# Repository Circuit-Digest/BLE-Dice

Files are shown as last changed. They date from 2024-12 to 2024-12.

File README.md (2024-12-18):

# [BLE-Dice](https://circuitdigest.com/microcontroller-projects/how-to-build-a-smart-led-dice)
An electronics dice with BluetoothLE connectivity.
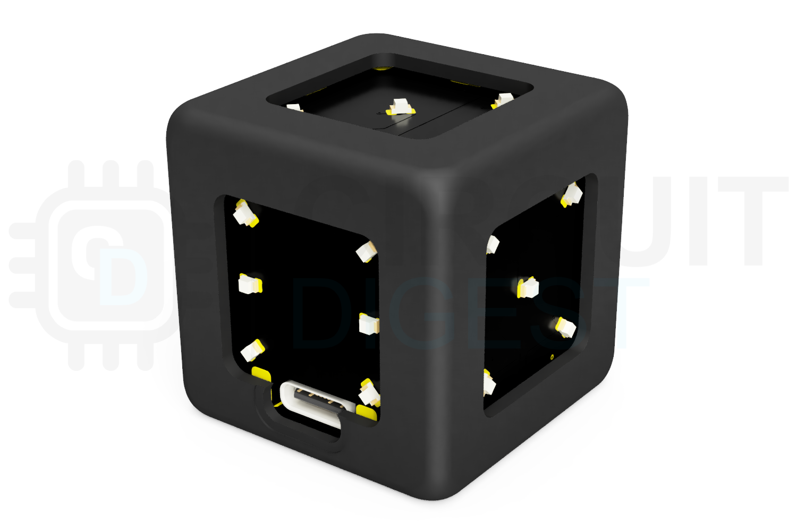
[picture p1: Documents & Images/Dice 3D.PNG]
image_tooltip

<br>

<br>

<br>

[<h1>Click here](https://circuitdigest.com/tags/ESP32) For other ESP32 tutorials.</h1>

<br>
<br>
<br>

<br>
[Note: As this project is very simple we are only providing the code, schematic, and a few essential images if you want to get the images or code explanations do check out the Circuit Digest website.
<br>
<br>

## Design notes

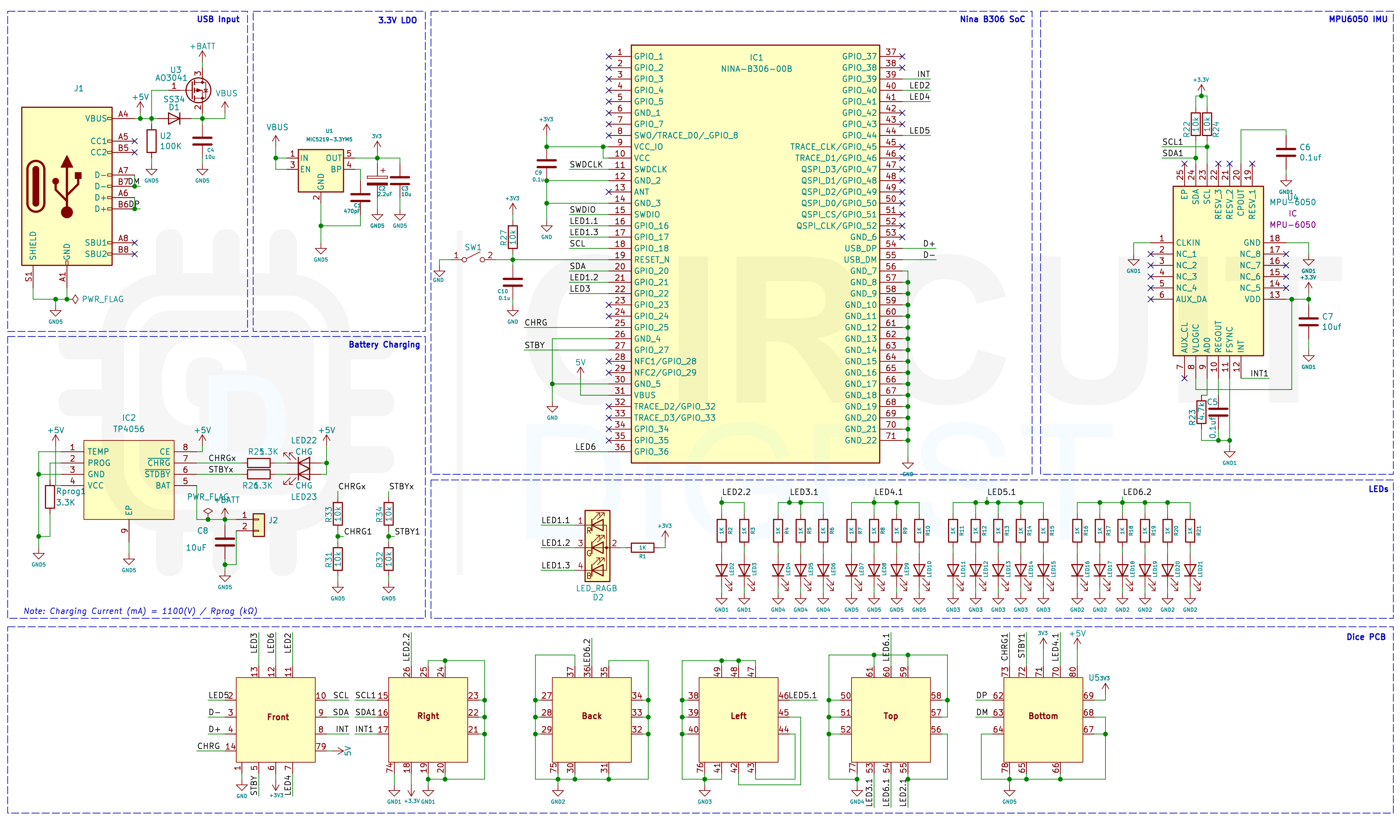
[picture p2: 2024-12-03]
Documents & Images/BLE Dice Schematics.png

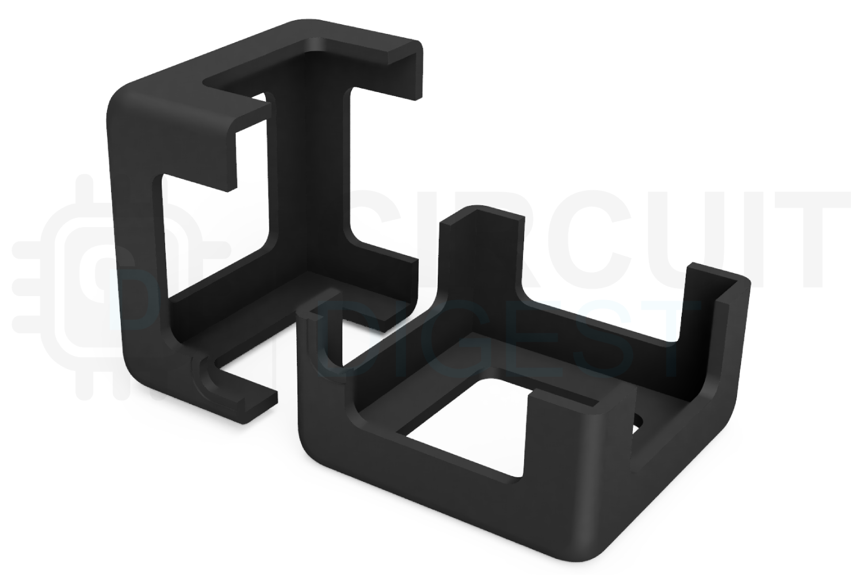
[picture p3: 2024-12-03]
Documents & Images/Dice2_Enc.png

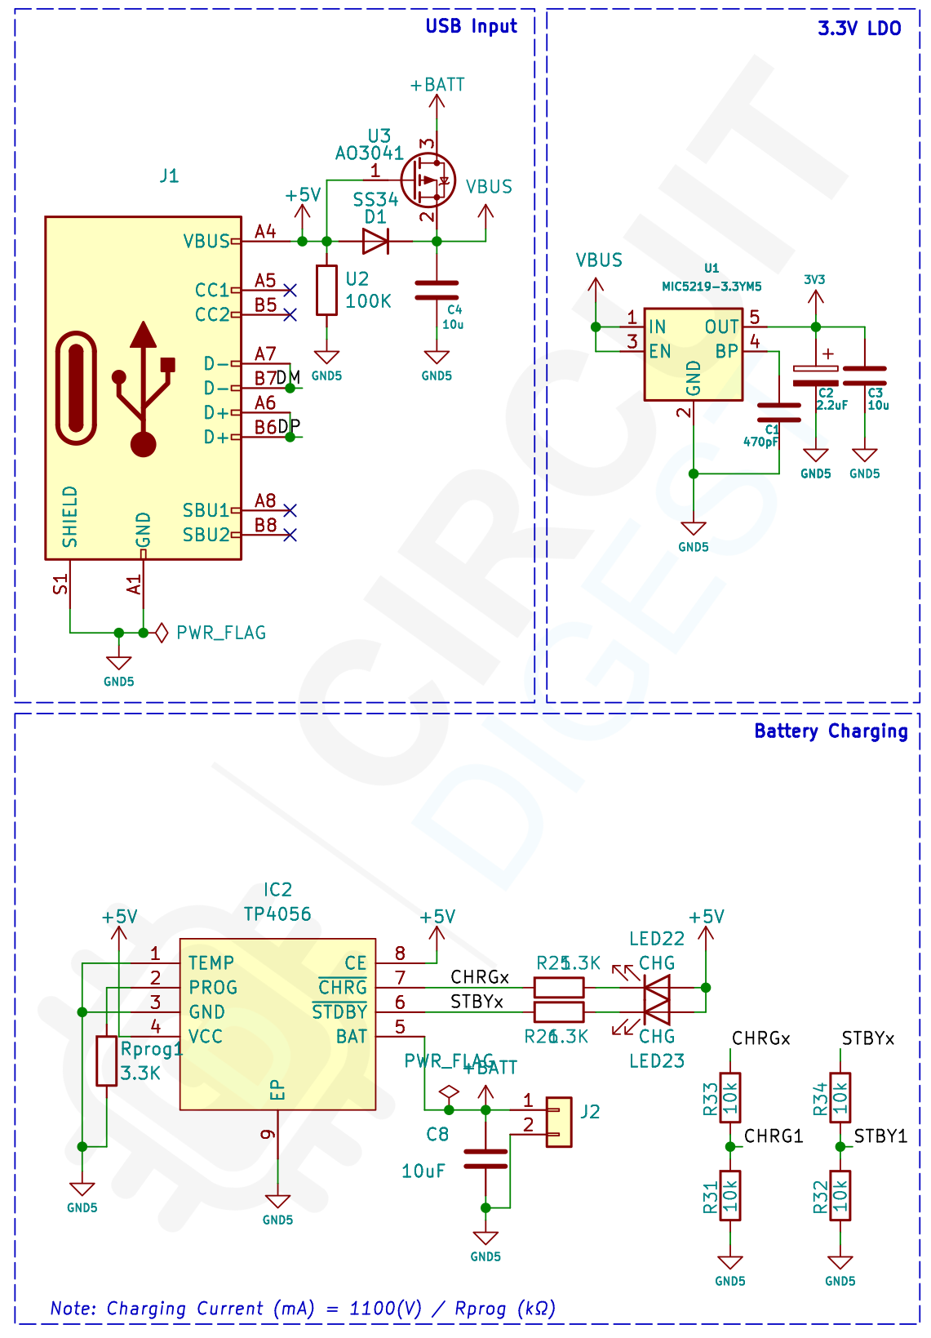
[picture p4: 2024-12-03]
Documents & Images/BLE Dice Power.png

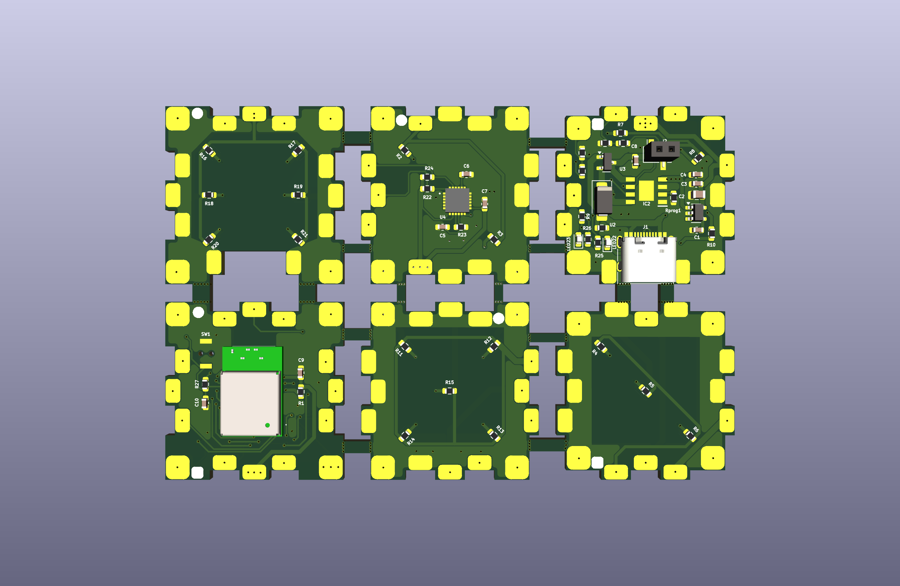
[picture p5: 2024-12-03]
Documents & Images/DiceTop3D.png

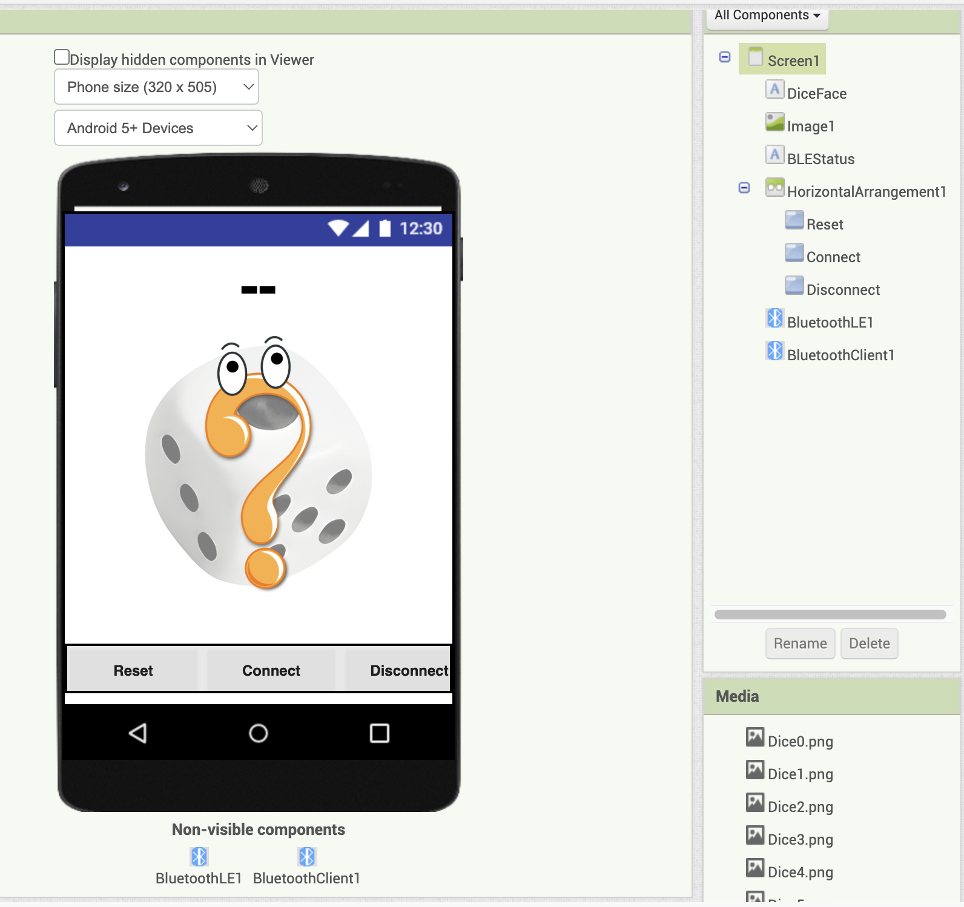
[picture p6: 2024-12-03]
Documents & Images/BLE Dice MIT app Invenotr UI.png

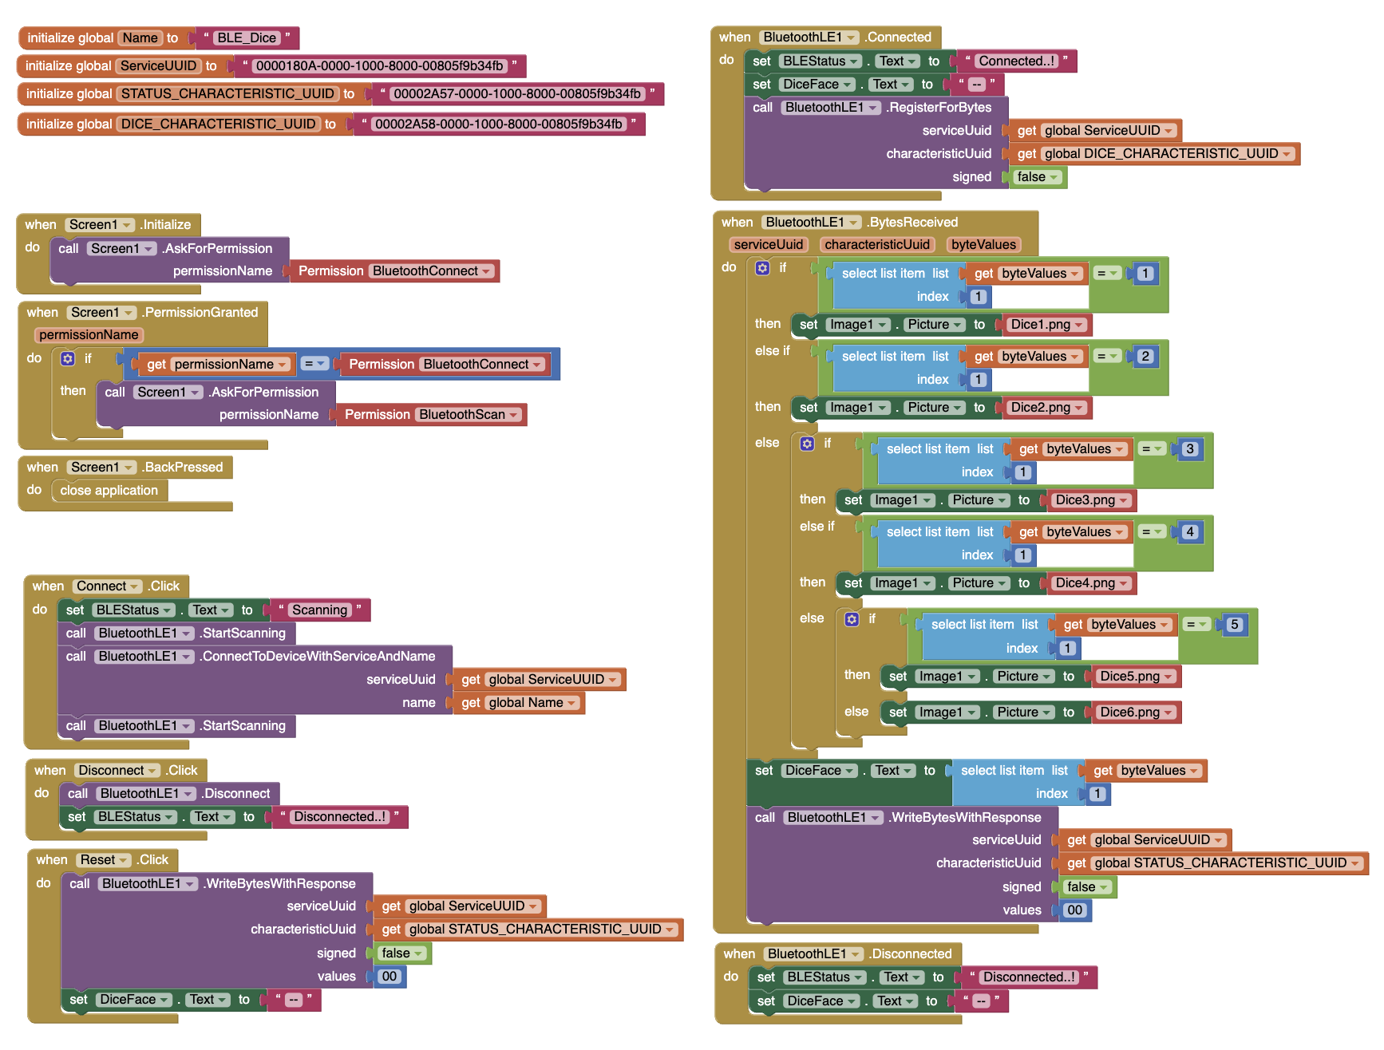
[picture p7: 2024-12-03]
Documents & Images/BLE Dice MIT App inventor Blocks.png

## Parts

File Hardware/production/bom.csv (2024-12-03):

Designator | Footprint | Quantity | Value | LCSC Part #
C1 | 0603 | 1 | 470pF
C10, C9 | 0603 | 2 | 0.1u
C2 | 0805 | 1 | 2.2uF
C3, C4 | 0603 | 2 | 10u
C5, C6 | 0603 | 2 | 0.1uf
C7, C8 | 0603 | 2 | 10uf
D1 | D_SMA | 1 | SS34
D2 | LED-ARRAY-SMD_4P-L1.6-W1.5-BR_XL-1615RGBC-RF | 1 | LED_RAGB
IC1 | NINAB30600B | 1 | NINA-B306-00B
IC2 | SOIC127P600X175-9N | 1 | TP4056
J1 | USB_C_Receptacle_HRO_TYPE-C-31-M-12 | 1 | USB_C_Receptacle_USB2.0
J2 | PinSocket_1x02_P2.00mm_Vertical_SMD_Pin1Right | 1 | B2B-PH-SM4-TB(LF)(SN)
LED10, LED11, LED12, LED13, LED14, LED15, LED16, LED17, LED18, LED19, LED2, LED20, LED21, LED3, LED4, LED5, LED6, LED7, LED8, LED9 | 0805 | 20 | POW_LED
LED22, LED23 | 0603 | 2 | CHG
R1, R10, R11, R12, R13, R14, R15, R16, R17, R18, R19, R2, R20, R21, R3, R4, R5, R6, R7, R8, R9 | 0603 | 21 | 1K
R22, R24, R27, R31, R32, R33, R34 | 0603 | 7 | 10k
R23 | 0603 | 1 | 4.7k
R25, R26 | 0603 | 2 | 1.3K
Rprog1 | 0603 | 1 | 3.3K
SW1 | Tactile 3x4x2mm TS-A010 | 1 | TS-1088R-02526
U1 | SOT-23-5 | 1 | MIC5219-3.3YM5
U2 | 0603 | 1 | 100K
U3 | SOT-23 | 1 | AO3041
U4 | MPU6050 | 1 | MPU-6050
U5 | Cube | 1 | ~

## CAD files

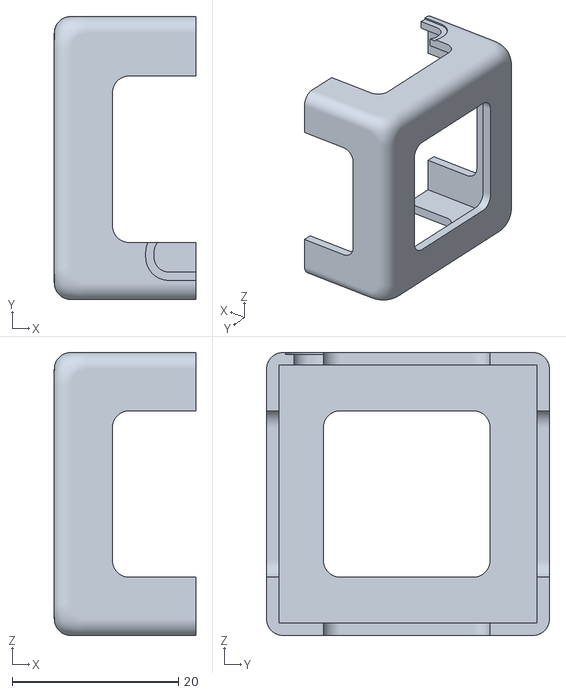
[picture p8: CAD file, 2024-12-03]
3D Printed Parts/Part2.stl
17.0 x 34.0 x 34.0

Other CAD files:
3D Printed Parts/Part1.stl

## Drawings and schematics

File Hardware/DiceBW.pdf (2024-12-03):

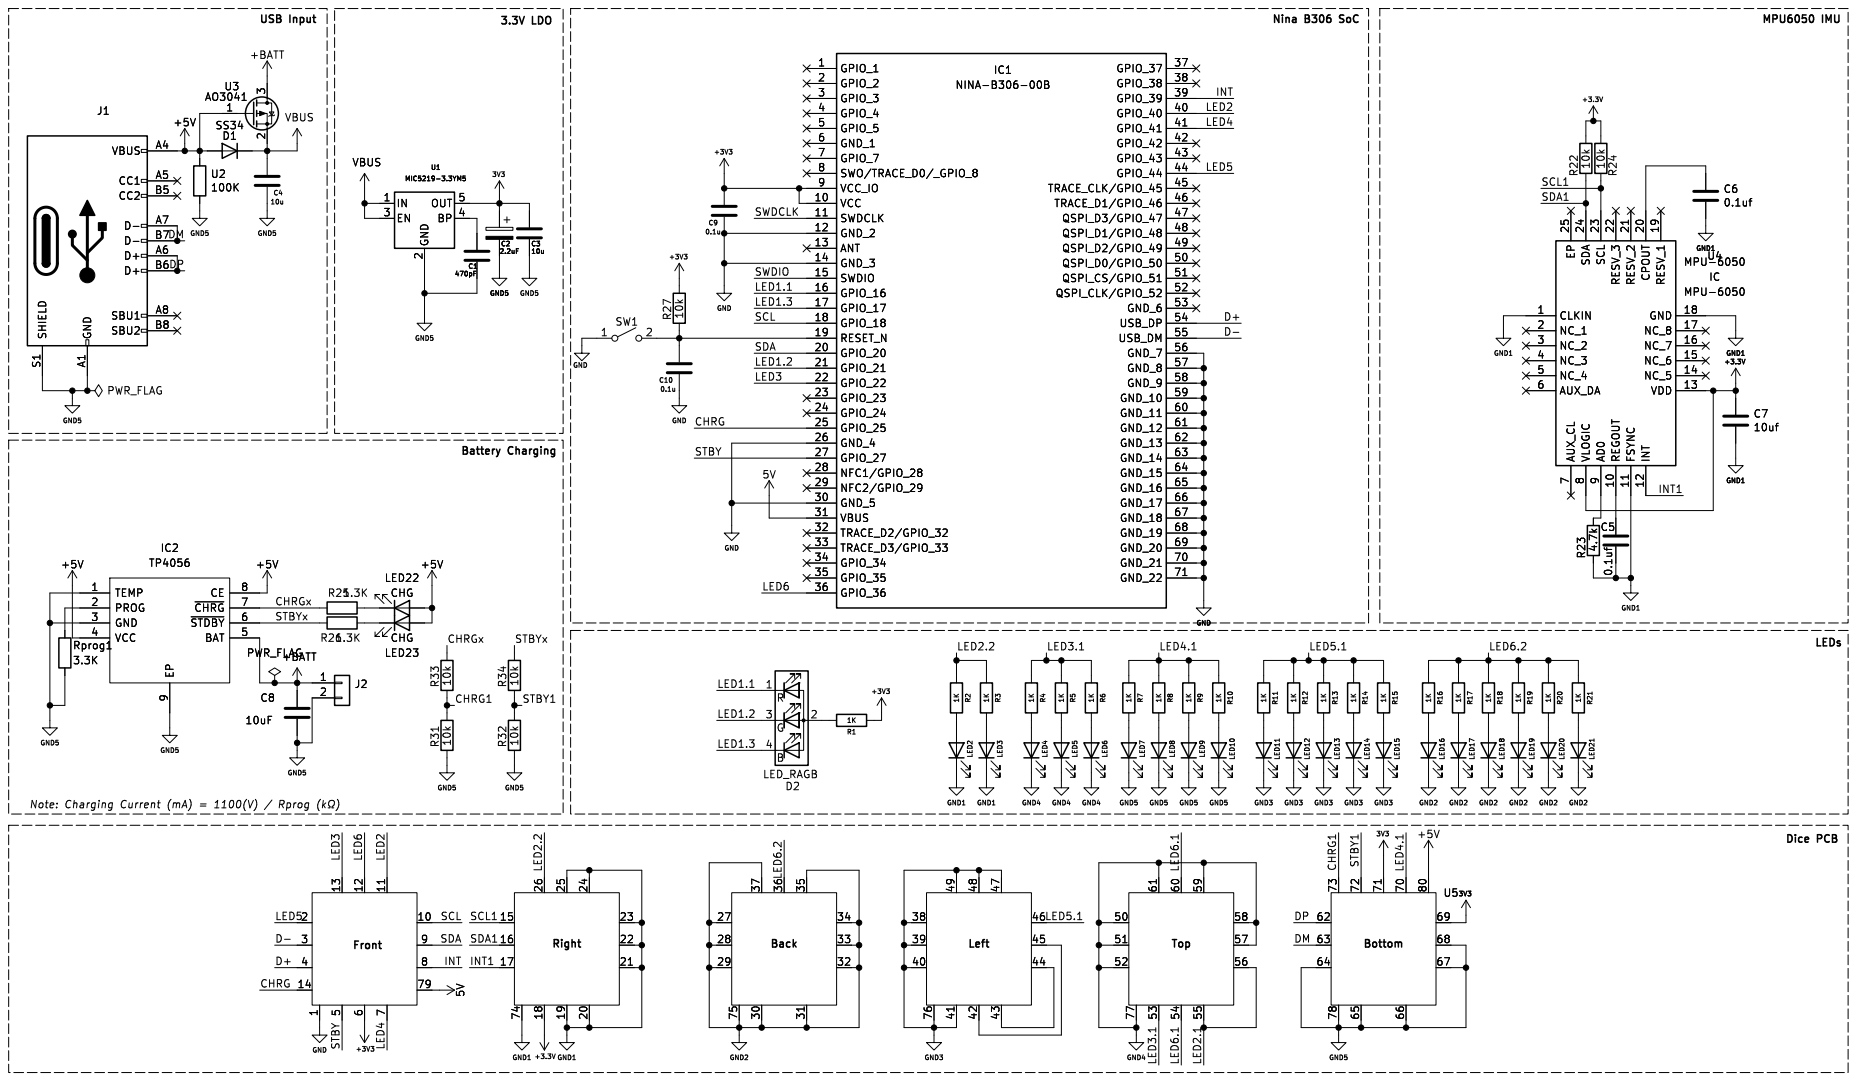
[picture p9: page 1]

Battery Charging USB Input

Note: Charging Current (mA) = 1100(V) / Rprog þÿ(k©)

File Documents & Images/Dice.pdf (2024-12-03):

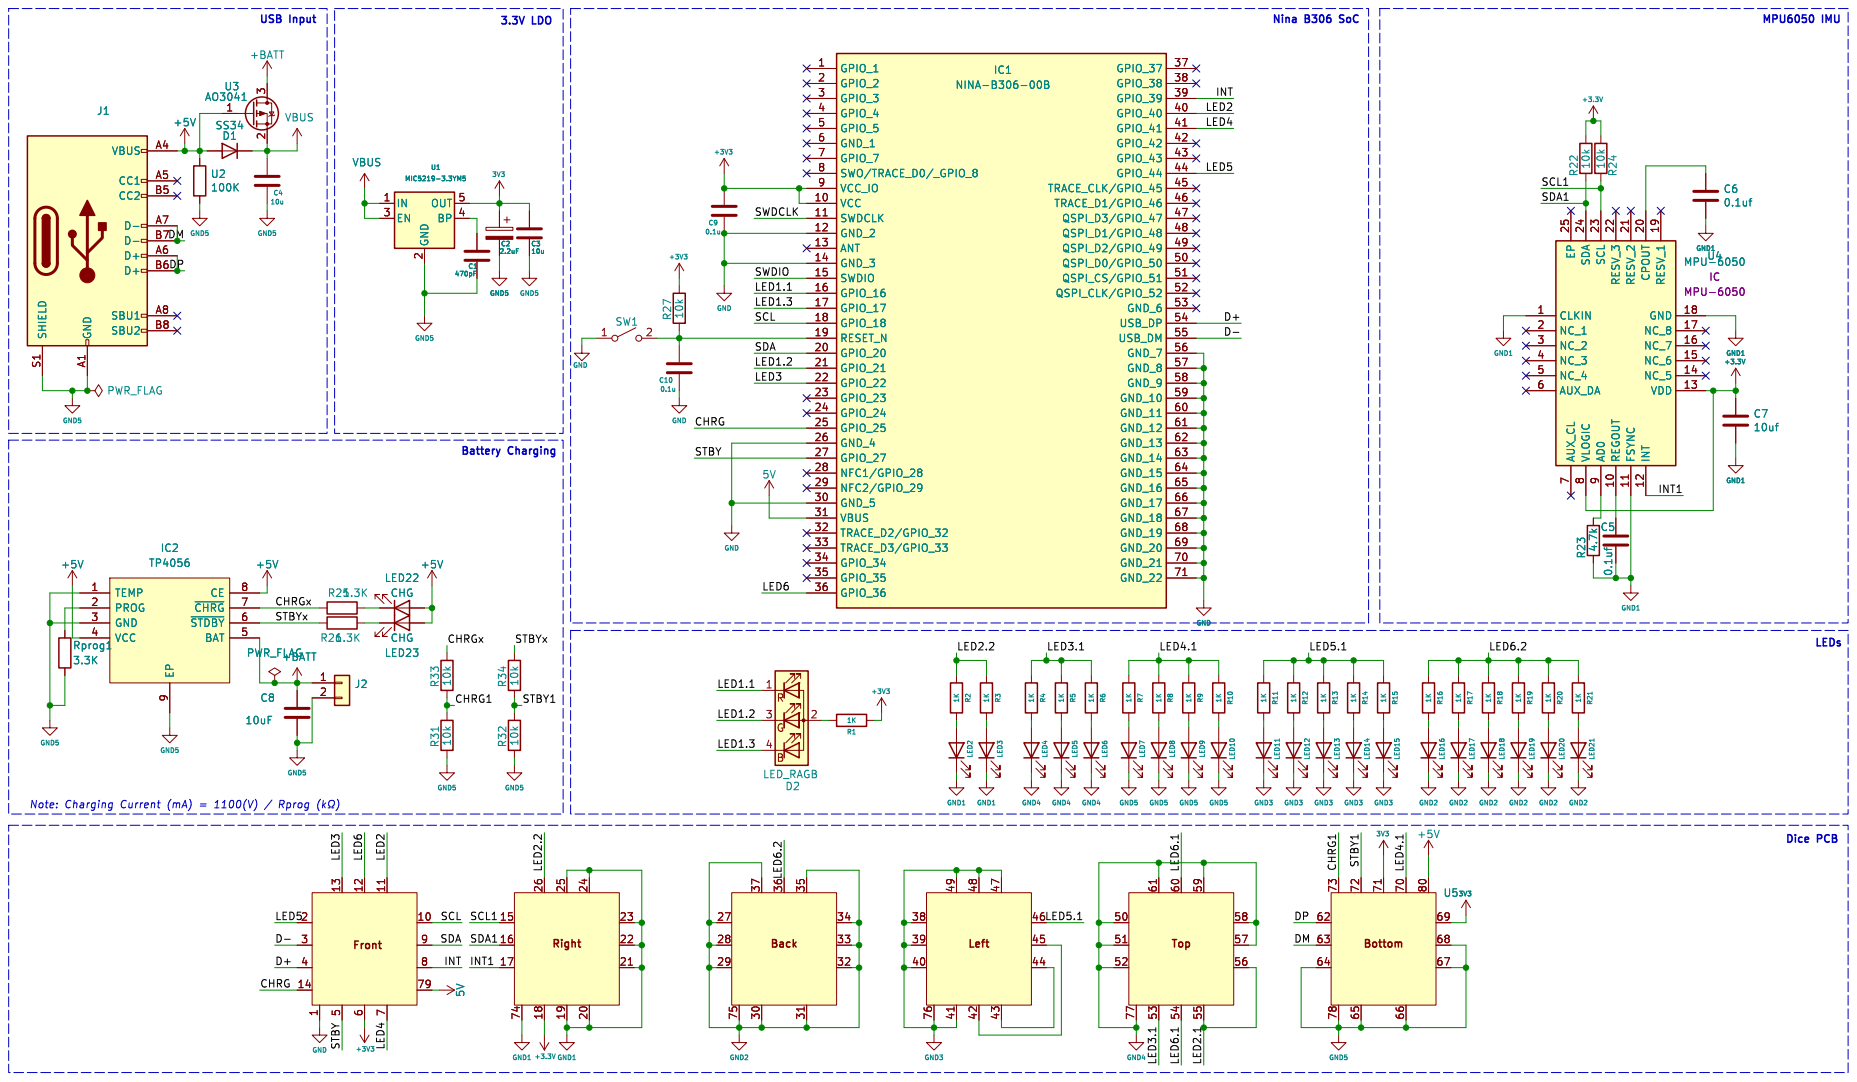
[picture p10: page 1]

Battery Charging USB Input
10u +BATT

2 EN 3 BP 4 OUT 5 VBUS

Note: Charging Current (mA) = 1100(V) / Rprog þÿ(k©)

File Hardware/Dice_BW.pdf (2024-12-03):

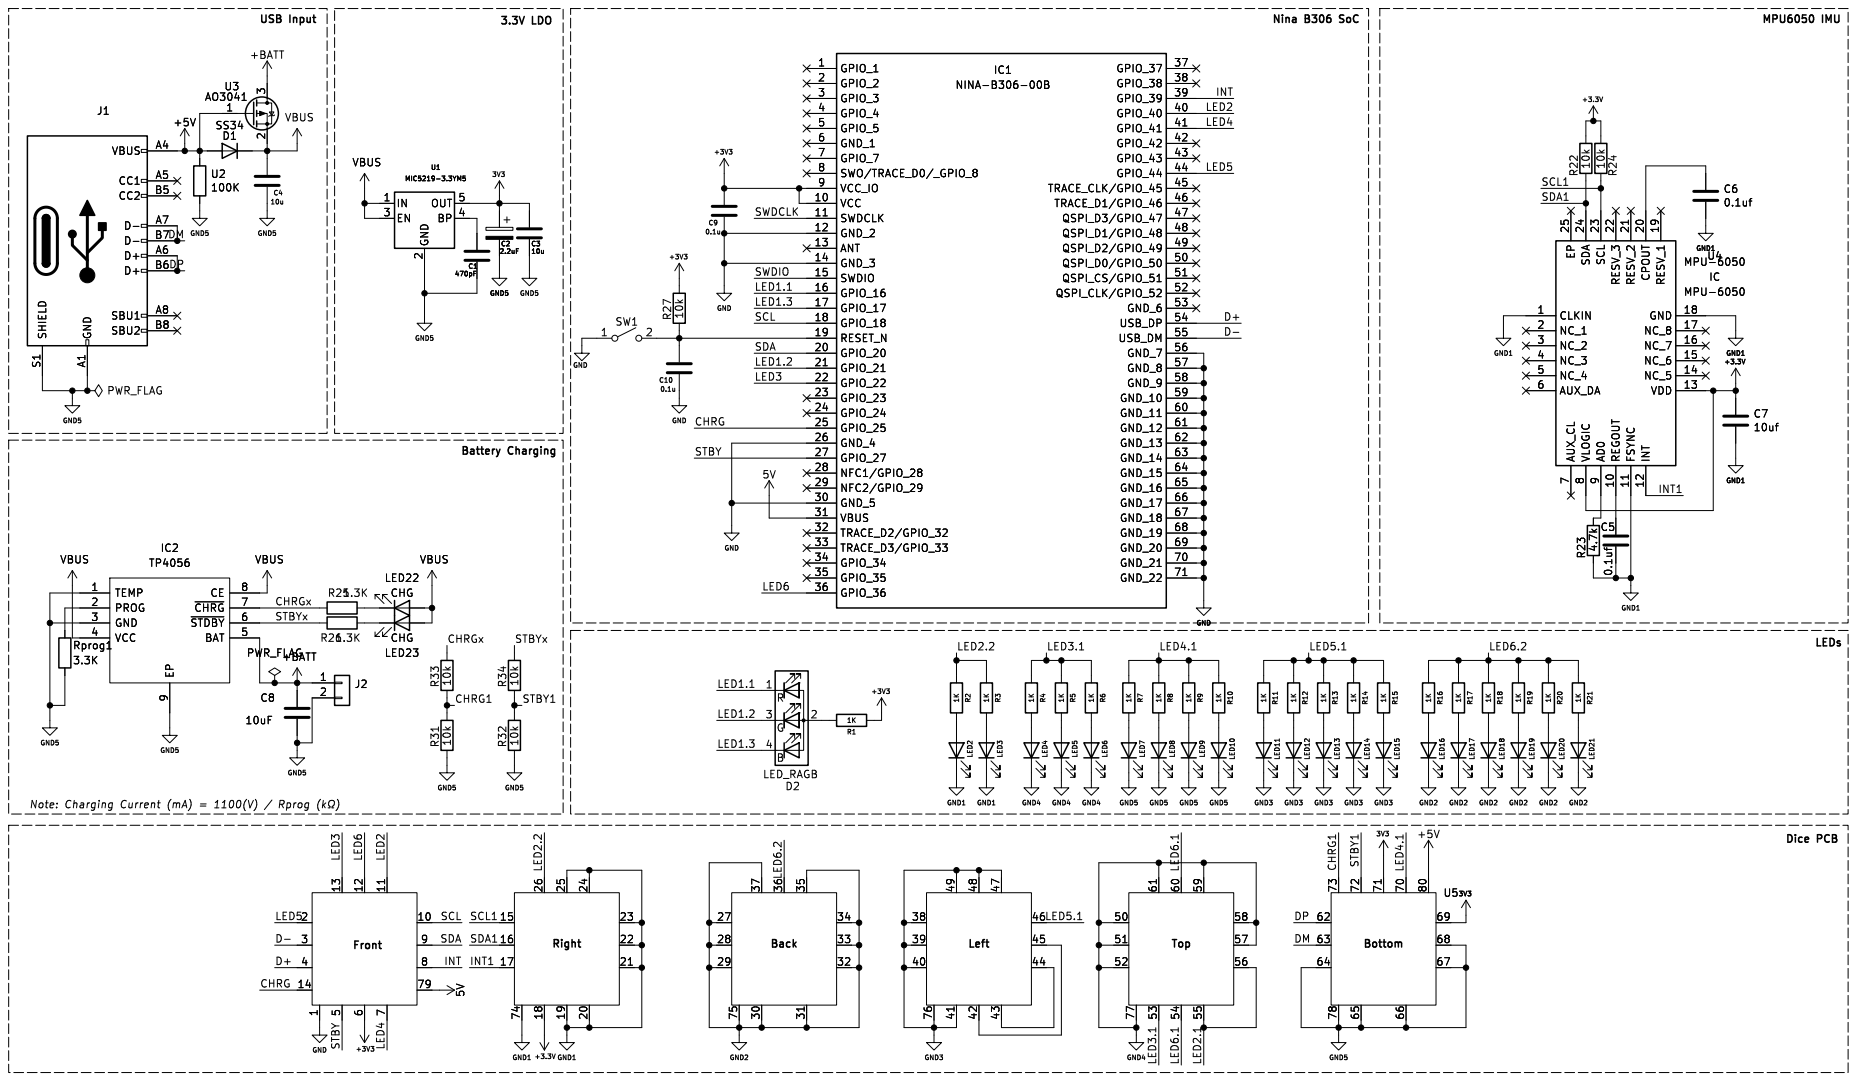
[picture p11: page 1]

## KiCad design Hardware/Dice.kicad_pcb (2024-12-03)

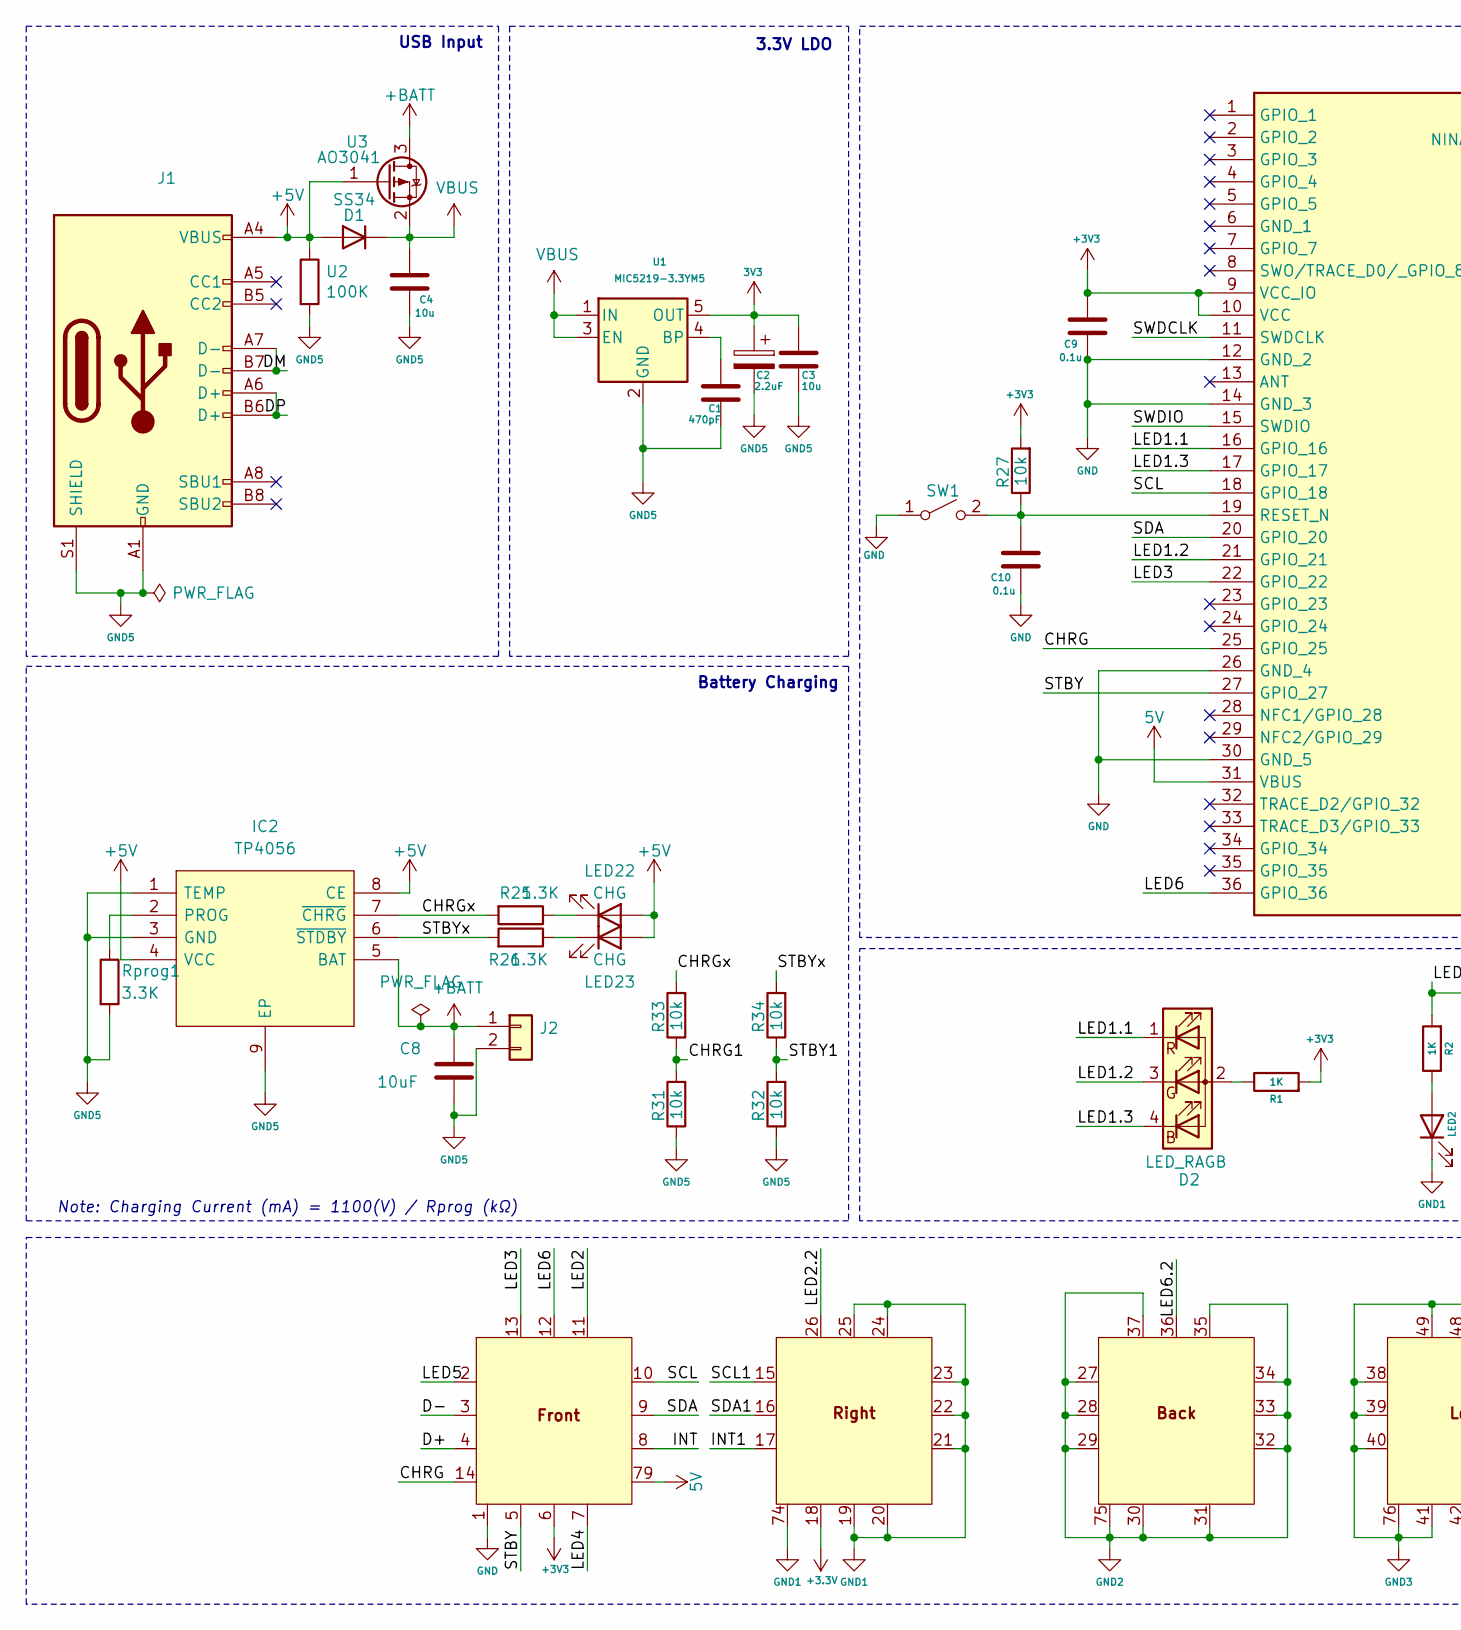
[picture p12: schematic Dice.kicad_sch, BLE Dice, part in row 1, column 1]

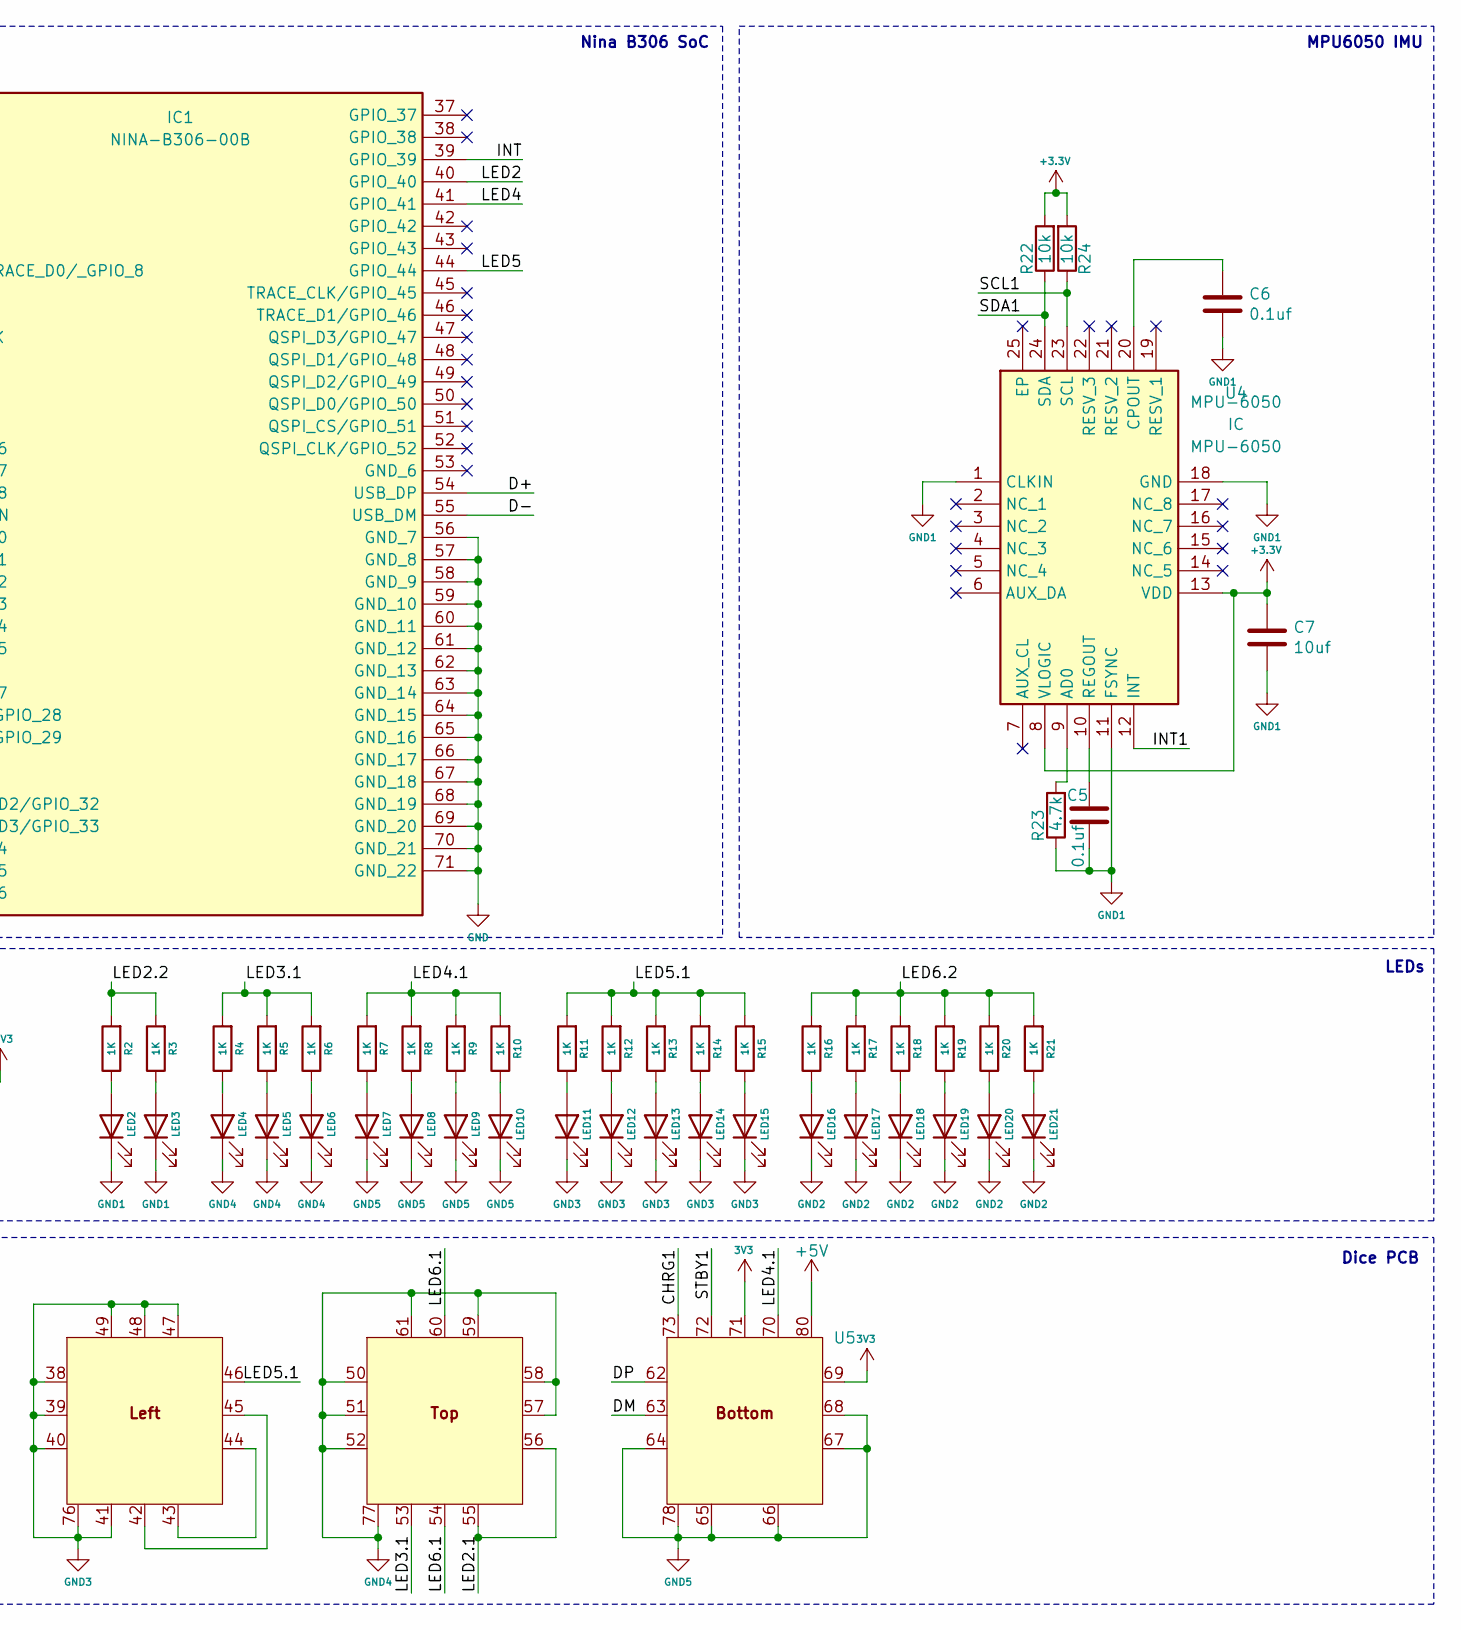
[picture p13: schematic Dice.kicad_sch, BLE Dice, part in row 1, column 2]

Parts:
C1: 470pF; C_0603_1608Metric
C2: 2.2uF; C_0805_2012Metric
C3, C4: 10u; C_0603_1608Metric
C5, C6: 0.1uf; C_0603_1608Metric
C7: 10uf; C_0603_1608Metric
C8: 10uF; C_0603_1608Metric
C9, C10: 0.1u; C_0603_1608Metric
D1: SS34; D_SMA
D2: LED_RAGB; LED-ARRAY-SMD_4P-L1.6-W1.5-BR_XL-1615RGBC-RF
IC1: NINA-B306-00B; NINAB30600B; Mouser Part Number 377-NINA-B306-00B
IC2: TP4056; SOIC127P600X175-9N; Manufacturer_Part_Number TP4056-42-ESOP8
J1: USB_C_Receptacle_USB2.0; USB_C_Receptacle_HRO_TYPE-C-31-M-12
J2: B2B-PH-SM4-TB(LF)(SN); PinSocket_1x02_P2.00mm_Vertical_SMD_Pin1Right
LED2, LED3, LED4, LED5, LED6, LED7, LED8, LED9, LED10, LED11, LED12, LED13, LED14, LED15, LED16, LED17, LED18, LED19, LED20, LED21: POW_LED; LED_0805_2012Metric
LED22, LED23: CHG; LED_0603_1608Metric
R1, R2, R3, R4, R5, R6, R7, R8, R9, R10, R11, R12, R13, R14, R15, R16, R17, R18, R19, R20, R21: 1K; R_0603_1608Metric
R22, R24, R27, R31, R32, R33, R34: 10k; R_0603_1608Metric
R23: 4.7k; R_0603_1608Metric
R25, R26: 1.3K; R_0603_1608Metric
Rprog1: 3.3K; R_0603_1608Metric
SW1: TS-1088R-02526; Tactile 3x4x2mm TS-A010
U1: MIC5219-3.3YM5; SOT-23-5
U2: 100K; R_0603_1608Metric
U3: AO3041; SOT-23
U4: MPU-6050; MPU6050; Mouser Part Number 410-MPU-6050
U5: Cube

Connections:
3V3: C2.1, C3.1, U1.5 (OUT), U5.69, U5.71
5V: IC1.31 (VBUS), U5.79
+3.3V: C7.1, R22.2, R24.2, U4.8 (VLOGIC), U4.13 (VDD), U5.18
+3V3: C9.1, IC1.9 (VCC_IO), IC1.10 (VCC), R1.2, R27.2, U5.6
+5V: D1.2 (A), IC2.4 (VCC), IC2.8 (CE), J1.A4 (VBUS), J1.A9 (VBUS), J1.B4 (VBUS), J1.B9 (VBUS), LED22.2 (A), LED23.2 (A), U2.1, U3.1 (G), U5.80
+BATT: C8.1, IC2.5 (BAT), J2.1, U3.3 (D)
/CHRG: IC1.25 (GPIO_25), U5.14
/CHRG1: R31.2, R33.1, U5.73
/CHRGx: IC2.7 (~CHRG), R25.2, R33.2
/D+: IC1.54 (USB_DP), U5.4
/D-: IC1.55 (USB_DM), U5.3
/DM: J1.A7 (D-), J1.B7 (D-), U5.63
/DP: J1.A6 (D+), J1.B6 (D+), U5.62
/INT: IC1.39 (GPIO_39), U5.8
/INT1: U4.12 (INT), U5.17
/LED1.1: D2.1 (RK), IC1.16 (GPIO_16)
/LED1.2: D2.3 (GK), IC1.21 (GPIO_21)
/LED1.3: D2.4 (BK), IC1.17 (GPIO_17)
/LED2: IC1.40 (GPIO_40), U5.11
/LED2.1: U5.55, U5.56
/LED2.2: R2.2, R3.2, U5.26
/LED3: IC1.22 (GPIO_22), U5.13
/LED3.1: R4.2, R5.2, R6.2, U5.53
/LED4: IC1.41 (GPIO_41), U5.7
/LED4.1: R7.2, R8.2, R9.2, R10.2, U5.70
/LED5: IC1.44 (GPIO_44), U5.2
/LED5.1: R11.2, R12.2, R13.2, R14.2, R15.2, U5.46
/LED6: IC1.36 (GPIO_36), U5.12
/LED6.1: U5.54, U5.60
/LED6.2: R16.2, R17.2, R18.2, R19.2, R20.2, R21.2, U5.36
/SCL: IC1.18 (GPIO_18), U5.10
/SCL1: R24.1, U4.23 (SCL), U5.15
/SDA: IC1.20 (GPIO_20), U5.9
/SDA1: R22.1, U4.24 (SDA), U5.16
/STBY: IC1.27 (GPIO_27), U5.5
/STBY1: R32.2, R34.1, U5.72
/STBYx: IC2.6 (~STDBY), R26.2, R34.2
/SWDCLK: IC1.11 (SWDCLK)
/SWDIO: IC1.15 (SWDIO)
GND: C9.2, C10.2, IC1.12 (GND_2), IC1.14 (GND_3), IC1.26 (GND_4), IC1.30 (GND_5), IC1.56 (GND_7), IC1.57 (GND_8), IC1.58 (GND_9), IC1.59 (GND_10), IC1.60 (GND_11), IC1.61 (GND_12), IC1.62 (GND_13), IC1.63 (GND_14), IC1.64 (GND_15), IC1.65 (GND_16), IC1.66 (GND_17), IC1.67 (GND_18), IC1.68 (GND_19), IC1.69 (GND_20), IC1.70 (GND_21), IC1.71 (GND_22), SW1.1 (A), U5.1
GND1: C5.2, C6.2, C7.2, LED2.1 (K), LED3.1 (K), R23.1, U4.1 (CLKIN), U4.11 (FSYNC), U4.18 (GND), U5.19, U5.20, U5.21, U5.22, U5.23, U5.24, U5.25, U5.74
GND2: LED16.1 (K), LED17.1 (K), LED18.1 (K), LED19.1 (K), LED20.1 (K), LED21.1 (K), U5.27, U5.28, U5.29, U5.30, U5.31, U5.32, U5.33, U5.34, U5.35, U5.37, U5.75
GND3: LED11.1 (K), LED12.1 (K), LED13.1 (K), LED14.1 (K), LED15.1 (K), U5.38, U5.39, U5.40, U5.41, U5.47, U5.48, U5.49, U5.76
GND4: LED4.1 (K), LED5.1 (K), LED6.1 (K), U5.50, U5.51, U5.52, U5.57, U5.58, U5.59, U5.61, U5.77
GND5: C1.2, C2.2, C3.2, C4.2, C8.2, IC2.1 (TEMP), IC2.3 (GND), IC2.9 (EP), J1.A1 (GND), J1.A12 (GND), J1.B1 (GND), J1.B12 (GND), J1.S1 (SHIELD), J2.2, LED7.1 (K), LED8.1 (K), LED9.1 (K), LED10.1 (K), R31.1, R32.1, Rprog1.2, U1.2 (GND), U2.2, U5.64, U5.65, U5.66, U5.67, U5.68, U5.78
unnamed: D2.2 (A), R1.1
unnamed: C10.1, IC1.19 (RESET_N), R27.1, SW1.2 (B)
unnamed: IC2.2 (PROG), Rprog1.1
unnamed: LED2.2 (A), R2.1
unnamed: LED3.2 (A), R3.1
unnamed: LED4.2 (A), R4.1
unnamed: LED5.2 (A), R5.1
unnamed: LED6.2 (A), R6.1
unnamed: LED7.2 (A), R7.1
unnamed: LED8.2 (A), R8.1
unnamed: LED9.2 (A), R9.1
unnamed: LED10.2 (A), R10.1
unnamed: LED11.2 (A), R11.1
unnamed: LED12.2 (A), R12.1
unnamed: LED13.2 (A), R13.1
unnamed: LED14.2 (A), R14.1
unnamed: LED15.2 (A), R15.1
unnamed: LED16.2 (A), R16.1
unnamed: LED17.2 (A), R17.1
unnamed: LED18.2 (A), R18.1
unnamed: LED19.2 (A), R19.1
unnamed: LED20.2 (A), R20.1
unnamed: LED21.2 (A), R21.1
unnamed: LED22.1 (K), R25.1
unnamed: LED23.1 (K), R26.1
unnamed: C1.1, U1.4 (BP)
unnamed: R23.2, U4.9 (AD0)
unnamed: C6.1, U4.20 (CPOUT)
unnamed: C5.1, U4.10 (REGOUT)
unnamed: U5.42, U5.45
unnamed: U5.43, U5.44
VBUS: C4.1, D1.1 (K), U1.1 (IN), U1.3 (EN), U3.2 (S)

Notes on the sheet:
Nina B306 SoC
MPU6050 IMU
Note: Charging Current (mA) = 1100(V) / Rprog (kΩ)
Battery Charging
USB Input
3.3V LDO
LEDs
Dice PCB

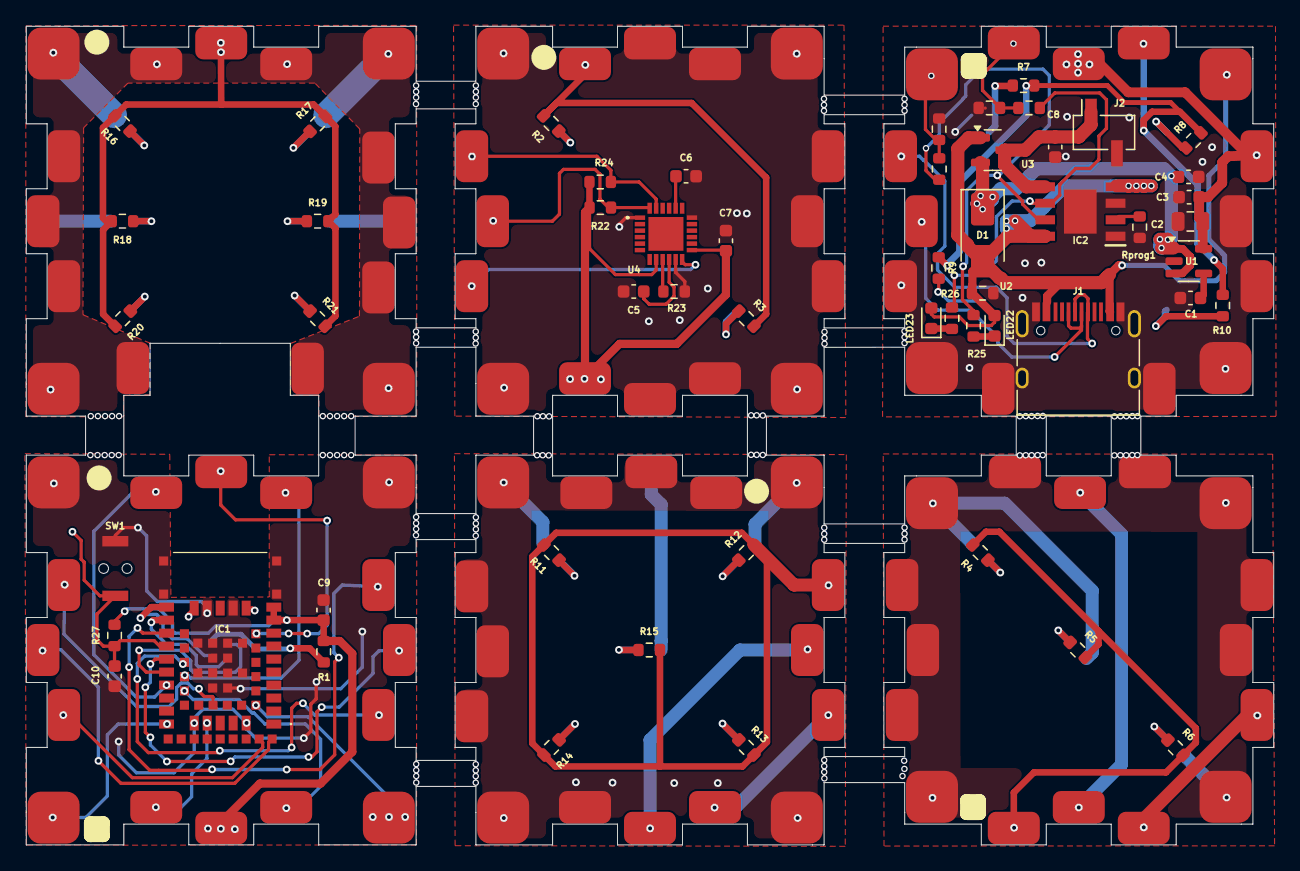
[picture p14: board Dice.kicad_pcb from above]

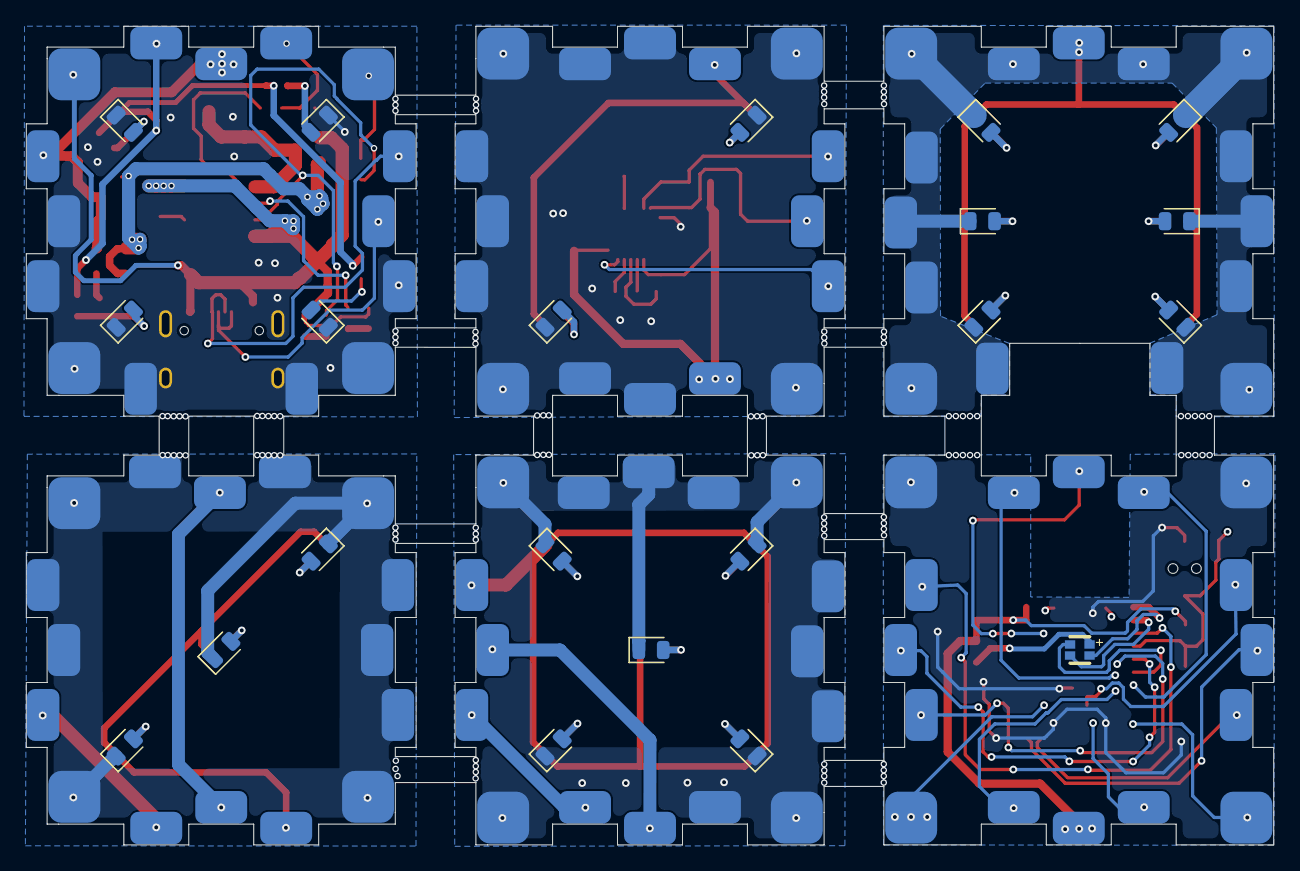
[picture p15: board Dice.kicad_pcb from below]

Board: 2 copper layers, 96.0 x 63.0 mm, 76 parts (21 on the bottom side), 75 nets.

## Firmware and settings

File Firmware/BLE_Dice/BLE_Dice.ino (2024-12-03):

/*
 * Project Name: BLE Dice
 * Project Brief: nRF52840 based Bluetooth LE Dice.
 * Author: Jobit Joseph @ https://github.com/jobitjoseph
 * IDE: Arduino IDE 2.x.x
 * Arduino Core: ESP32 Arduino Core V 3.0.7
 * Dependencies : ArduinoBLE Library V 1.3.7 @ https://github.com/arduino-libraries/ArduinoBLE
 *                Adafruit MPU6050 Library V 2.2.6 @ https://github.com/adafruit/Adafruit_MPU6050
 * Copyright © Jobit Joseph
 * Copyright © Semicon Media Pvt Ltd
 * Copyright © Circuitdigest.com
 * 
 * This code is licensed under the following conditions:
 *
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
 * 2. Commercial Use:
 * For any commercial use of this software, you must obtain a separate license
 * from the original author. Contact the author for permissions or licensing
 * options before using this software for commercial purposes.
 *
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
 * Author: Jobit Joseph
 * Date: 18 October 2024
 *
 * For commercial use or licensing requests, please contact [jobitjoseph1@gmail.com].
 */
#include <Wire.h>
#include <Adafruit_MPU6050.h>
#include <Adafruit_Sensor.h>
#include <ArduinoBLE.h>

// Pin definitions
#define rgbRed A7
#define rgbGreen A6
#define rgbBlue 3
#define leftLEDs 4
#define rightLEDs 9
#define backLEDs 10
#define bottomLEDs 6
#define topLEDs 5

Adafruit_MPU6050 mpu;

// Variables for shake and stationary detection
float shakeThreshold = 15.0; // Adjust for shake sensitivity
float stationaryThreshold = 15.0; // Threshold for being stationary
unsigned long stationaryDuration = 1500; // Duration to confirm stationary (in ms)

// BLE Characteristics
BLEService diceService("180A");//0000180A-0000-1000-8000-00805f9b34fb
BLEByteCharacteristic statusCharacteristic("2A57", BLERead | BLEWrite | BLENotify);//00002A58-0000-1000-8000-00805f9b34fb
BLEByteCharacteristic faceCharacteristic("2A58", BLERead | BLENotify);//00002A57-0000-1000-8000-00805f9b34fb

// Other Variables
int currentFace = -1; // Tracks the current face
unsigned long lastStationaryTime = 0;
unsigned long lastRGBBlinkTime = 0;
bool BLEStatus = false;
int LEDPins[7] = {-1,A6, 4, 5, 6, 9,10};

enum DiceState {
  WAIT_FOR_SHAKE,
  WAIT_FOR_STATIONARY,
  UPDATE_FACE,
  WAIT_FOR_BLE_RESET
};

DiceState currentState = WAIT_FOR_SHAKE; // Start in the WAIT_FOR_SHAKE state
unsigned long lastFlashTime = 0; // For non-blocking sequential LED flashing
int flashIndex = 0; // Current LED index for sequential flashing
bool shakeDetected = false; // To track shake detection
unsigned long stationaryStartTime = 0; // Track time for stationary detection


void setup() {
  Serial.begin(115200);

  // Initialize MPU6050
  if (!mpu.begin()) {
    Serial.println("Failed to find MPU6050 chip");
    while (1);
  }
  Serial.println("MPU6050 Found!");

  mpu.setAccelerometerRange(MPU6050_RANGE_8_G);
  mpu.setFilterBandwidth(MPU6050_BAND_21_HZ);

  // Initialize LED pins
  pinMode(rgbRed, OUTPUT);
  pinMode(rgbGreen, OUTPUT);
  pinMode(rgbBlue, OUTPUT);
  pinMode(leftLEDs, OUTPUT);
  pinMode(rightLEDs, OUTPUT);
  pinMode(backLEDs, OUTPUT);
  pinMode(bottomLEDs, OUTPUT);
  pinMode(topLEDs, OUTPUT);

  turnOffAllLEDs(); // Ensure all LEDs are off at boot
  digitalWrite(rgbRed, LOW);
  // Initialize BLE
  if (!BLE.begin()) {
    Serial.println("Starting BLE failed!");
    while (1);
  }
  BLE.setLocalName("BLE_Dice");
  BLE.setAdvertisedService(diceService);

  diceService.addCharacteristic(statusCharacteristic);
  diceService.addCharacteristic(faceCharacteristic);

  BLE.addService(diceService);

  // Set characteristics to 0 at boot
  statusCharacteristic.writeValue(0);
  faceCharacteristic.writeValue(0);

  BLE.advertise();
  Serial.println("BLE_Dice is ready!");
  
}

void loop() {
  // Handle BLE
  BLEDevice central = BLE.central();
  if (central) {
    BLEStatus = true;
    Serial.print("Connected to: ");
    Serial.println(central.address());
    currentState = WAIT_FOR_SHAKE;
    statusCharacteristic.writeValue(0); // Dice ready
    faceCharacteristic.writeValue(0); // Detected face
    turnOffAllLEDs();
    while (central.connected()) {
      handleDiceLogic();
    }
    Serial.println("Disconnected from central");
    turnOffAllLEDs();
    BLEStatus = false;
    digitalWrite(rgbRed, LOW);
  }
  if(BLEStatus == false) {
  blinkRGB();
  }
}

void handleDiceLogic() {
  switch (currentState) {
    case WAIT_FOR_SHAKE:
      // Blink blue LED until shake is detected
      blinkBlueLED();
      if (detectShake()) {
        shakeDetected = true;
        digitalWrite(rgbBlue, HIGH); // Turn off blue LED
        currentState = WAIT_FOR_STATIONARY; // Move to next state
        Serial.println("Shake detected! Moving to WAIT_FOR_STATIONARY.");
      }
      break;

    case WAIT_FOR_STATIONARY:
      // Flash LEDs sequentially until stationary
      if (millis() - lastFlashTime >= 100) { // Non-blocking delay for LED flashing
        flashSequentialLEDs();
        lastFlashTime = millis();
      }
      if (detectStationary()) {
        currentState = UPDATE_FACE; // Move to next state
        Serial.println("Stationary detected! Moving to UPDATE_FACE.");
      }
      break;

    case UPDATE_FACE:
      // Determine face and update LEDs and BLE characteristics
      currentFace = determineFace();
      if(currentFace < 0)
      {
        return;
      }
      updateLEDs(currentFace);

      // Set BLE characteristics
      statusCharacteristic.writeValue(1); // Dice ready
      faceCharacteristic.writeValue(currentFace); // Detected face

      Serial.println("Face updated! Waiting for BLE reset.");
      currentState = WAIT_FOR_BLE_RESET; // Move to next state
      break;

    case WAIT_FOR_BLE_RESET:
      // Wait for user to set statusCharacteristic to 0
      if (statusCharacteristic.value() == 0) {
        turnOffAllLEDs(); // Reset LEDs before next cycle
        currentState = WAIT_FOR_SHAKE; // Go back to initial state
        Serial.println("BLE reset! Returning to WAIT_FOR_SHAKE.");
      }
      break;
  }
}

bool detectShake() {
  sensors_event_t a, g, temp;
  mpu.getEvent(&a, &g, &temp);

  float magnitude = sqrt(a.acceleration.x * a.acceleration.x +
                         a.acceleration.y * a.acceleration.y +
                         a.acceleration.z * a.acceleration.z);

  if (magnitude > shakeThreshold) {
    Serial.println("Shake detected!");
    return true;
  }
  return false;
}

bool detectStationary() {
  static float accelSum = 0;         // Sum of acceleration magnitudes
  static int sampleCount = 0;        // Number of samples in the averaging window

  sensors_event_t a, g, temp;
  mpu.getEvent(&a, &g, &temp);

  float magnitude = sqrt(a.acceleration.x * a.acceleration.x +
                         a.acceleration.y * a.acceleration.y +
                         a.acceleration.z * a.acceleration.z);

  // Add current magnitude to the sum
  accelSum += magnitude;
  sampleCount++;

  // Average the acceleration magnitude over the sample window
  float averageMagnitude = accelSum / sampleCount;

  if (averageMagnitude < stationaryThreshold) {
    if (millis() - lastStationaryTime > stationaryDuration) {
      // Reset for the next cycle
      accelSum = 0;
      sampleCount = 0;
      Serial.println("Stationary detected!");
      return true;
    }
  } else {
    // Reset stationary timer if movement is above the threshold
    lastStationaryTime = millis();
    accelSum = 0;
    sampleCount = 0;
  }

  return false;
}

int determineFace() {
  sensors_event_t a, g, temp;
  mpu.getEvent(&a, &g, &temp);

  if (a.acceleration.y > 8.0) return 3; // Top
  if (a.acceleration.y < -8.0) return 4; // Bottom
  if (a.acceleration.z > 8.0) return 5; // Right
  if (a.acceleration.z < -8.0) return 2; // Left
  if (a.acceleration.x > 8.0) return 6; // Back
  if (a.acceleration.x < -8.0) return 1; // Front
  return -1; // Unknown
}

void flashSequentialLEDs() {
  const int leds[] = {rgbGreen,leftLEDs, rightLEDs, backLEDs, bottomLEDs, topLEDs};
  for (int i = 0; i < 6; i++) {
    turnOffAllLEDs();
    if(i == 0)
    {
        digitalWrite(leds[i], LOW);
    }
    else {
        digitalWrite(leds[i], HIGH);
    }
    delay(100);
  }
}

void blinkBlueLED() {
  static unsigned long lastBlinkTime = 0;
  static bool ledState = false;

  if (millis() - lastBlinkTime >= 500) {
    ledState = !ledState;
    digitalWrite(LEDPins[currentFace], ledState ? LOW : HIGH);
    lastBlinkTime = millis();
  }
}

void blinkRGB() {

  if (millis() - lastRGBBlinkTime >= 200) {
    if(digitalRead(rgbRed) == 0)
    {
      digitalWrite(rgbRed, HIGH);
      digitalWrite(rgbBlue, HIGH);
      digitalWrite(rgbGreen, LOW);
    }
    else if(digitalRead(rgbGreen) == 0)
    {
      digitalWrite(rgbRed, HIGH);
      digitalWrite(rgbGreen, HIGH);
      digitalWrite(rgbBlue, LOW);
    }
    else if(digitalRead(rgbBlue) == 0)
    {
      digitalWrite(rgbBlue, HIGH);
      digitalWrite(rgbGreen, HIGH);
      digitalWrite(rgbRed, LOW);
    }
    lastRGBBlinkTime = millis();
  }
}

void updateLEDs(int face) {
  turnOffAllLEDs();
  if(face == 1)
  {
    digitalWrite(LEDPins[face], LOW);
  }
  else
  {
    digitalWrite(LEDPins[face], HIGH);
  }

}

void turnOffAllLEDs() {
  digitalWrite(rgbRed, HIGH); // Fully off for common anode
  digitalWrite(rgbGreen, HIGH);
  digitalWrite(rgbBlue, HIGH);
  digitalWrite(leftLEDs, LOW);
  digitalWrite(rightLEDs, LOW);
  digitalWrite(backLEDs, LOW);
  digitalWrite(bottomLEDs, LOW);
  digitalWrite(topLEDs, LOW);
}
